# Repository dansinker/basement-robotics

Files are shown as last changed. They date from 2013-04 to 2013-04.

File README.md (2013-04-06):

Basement Robotics: A 3d printed, arduino controlled robot arm
=================

My image

So I built a little robot arm in my basement. All the parts that aren't motors are 3d printed. This repo, like the arm itself, is still a work in progress.

What's in this Repo?
-----------
This repo contains all files necessary to print the 3d arm parts and to program your Arduino to control the arm. Naturally, you will need to consult the shopping list for the various bits and pieces you're going to need to actually build the thing. Most importantly, this repo contains
* [Knob_robotclaw.ino](https://github.com/sinker/basement-robotics/blob/master/Knob_robotclaw.ino) this is the sketch to load into your Arduino.
* [stl_files_for_arm](https://github.com/sinker/basement-robotics/tree/master/stl_files_for_arm) These are every STL file needed to create 3d prints of the arm parts. There are a lot of files that could probably be brought into Makerware (or equivalent) and printed together. I haven't created any massive grouped files just because so many of these pieces had to be build separately and tweaked until they were right.

What's not in this Repo?
-----------
Check the Todo List at the bottom.

Shopping list
---------
* 1 Arduino, obviously.
* A good-sized breadboard.
* 4 hobbyist small-servos. [I bought from Sparkfun](https://www.sparkfun.com/products/9065), and these fit snugly the arms.
* 1 small stepper motor. [Again, Sparkfun](https://www.sparkfun.com/products/10551), and the base is sized to precisely fit this motor.
* 1 stepper motor controller. The code in this sketch is for controlling the [EasyDriver Stepper Motor](https://www.sparkfun.com/products/10267).
* 4 potentiometers. I am using three knobs for wrist, elbow, and shoulder control, and then one slide pot for the claw. You could also use a joystick, or all sliders, or whatever you want. 
* Jumper cable extensions. You're going to be creating a ratsnest of cables and, if you want the arm to have full movement, you're going to need to extend the servo connections and the stepper motor wire at a bare minimum.

Alternate Designs
---------
**Servo for the Base Rotation** You could very easily modify the base to be servo-controlled instead of stepper controlled. This has a number of plusses, mainly centered around exact numerical control of position. I personally found that the servos I had felt a little under-powered for rotating the entire arm, and also didn't give me a full 180 degree of motion because of the gear ratio I was using. A stepper, at the end of the day, got the job done easier. 

**Rotational wrist** One thing I don't think I'm building, but would love to see, is a wrist that can be rotated across the claw's center access.

**Linear claw motion** I'm still going to work on this one. I would like to modify the claw design to open and close completely linearly instead of the more pincer-like current design. 

TODO LIST
--------

* ~~upload all stl files~~ and images of each piece
* ~~create shopping list~~
* create circuit diagram
* assembly instructions
* ~~alternative design thoughts~~

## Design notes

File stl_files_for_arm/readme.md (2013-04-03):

Hi there. 

So these are the final STL files used in the robot pictured at the root of this repo. They were all created in (soon-to-be-late, great) Tinkercad. I will include links to the Tinkercad files themselves in this Readme, but since, well, the fucking site is shutting down this year, these links won't be useful for long.

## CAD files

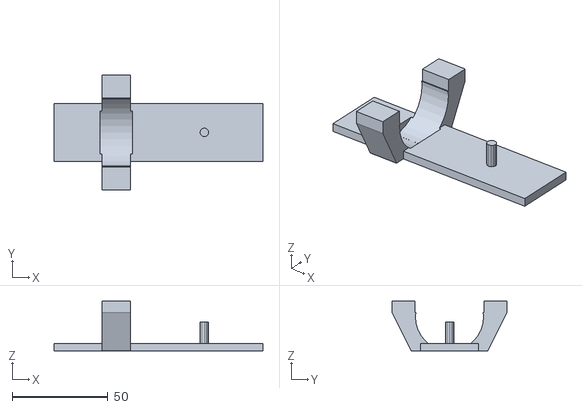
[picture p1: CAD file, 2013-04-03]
stl_files_for_arm/robot_arm_base_stepper.stl
109.0 x 60.0 x 26.0

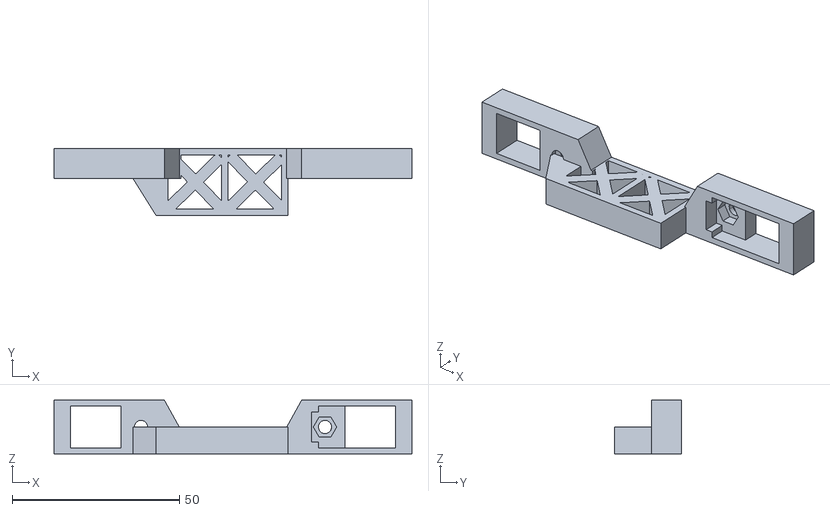
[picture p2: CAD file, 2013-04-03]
stl_files_for_arm/robot_arm_elbow__wrist.stl
107.0 x 20.0 x 16.0

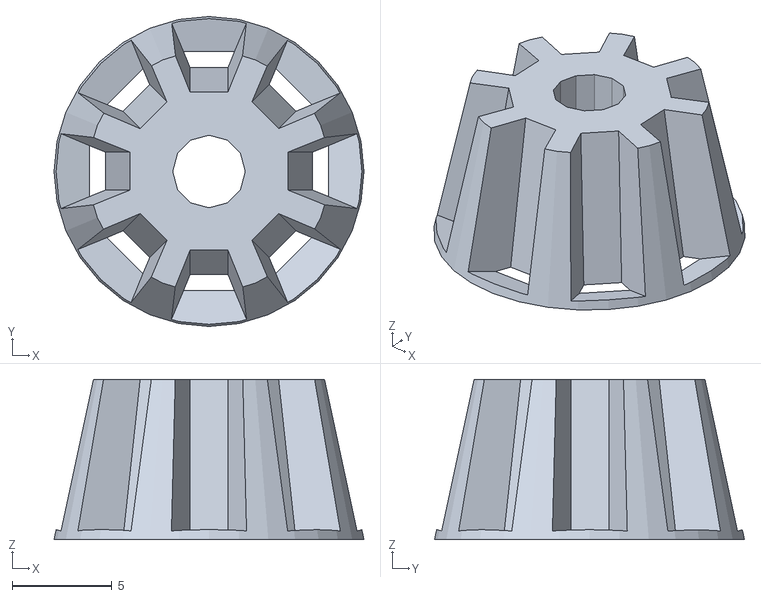
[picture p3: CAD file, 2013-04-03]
stl_files_for_arm/robot_base_rotation_gear.stl
15.5 x 15.5 x 8.00

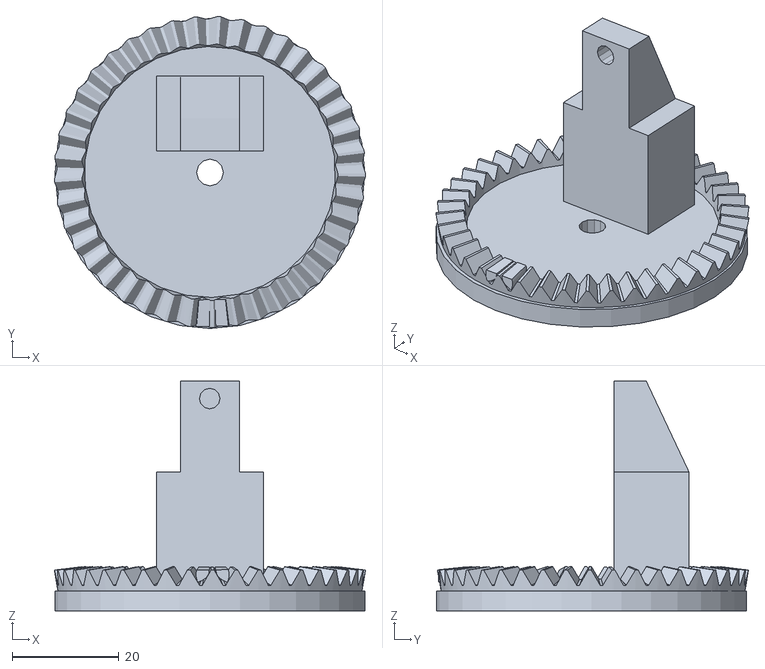
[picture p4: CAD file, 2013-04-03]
stl_files_for_arm/robot_arm_base_stepper_height.stl
58.2 x 58.4 x 43.0

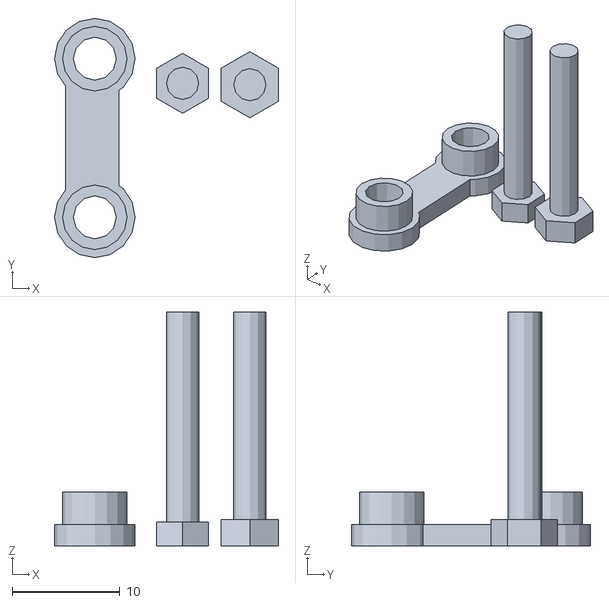
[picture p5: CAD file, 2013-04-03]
stl_files_for_arm/pins_to_connect_pincers.stl
20.8 x 22.2 x 21.8

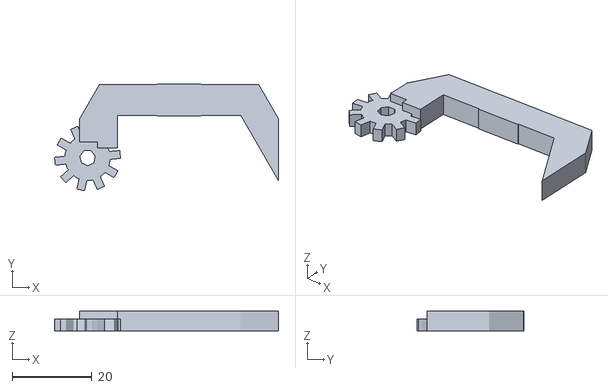
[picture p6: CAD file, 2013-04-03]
stl_files_for_arm/left_pincer.stl
56.3 x 26.8 x 5.00

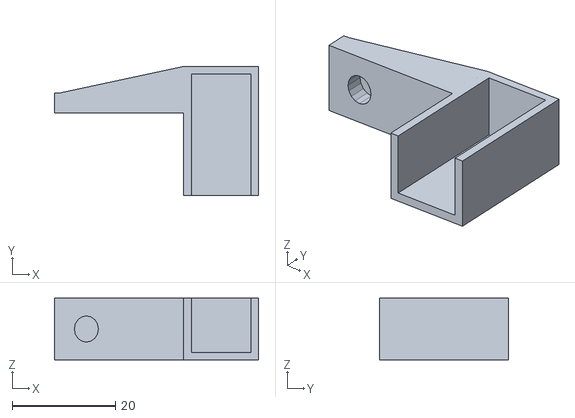
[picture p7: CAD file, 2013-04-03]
stl_files_for_arm/claw_holder.stl
39.5 x 25.0 x 12.0

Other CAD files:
stl_files_for_arm/right_pincer.stl

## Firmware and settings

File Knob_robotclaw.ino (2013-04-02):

// Controlling a servo position using a potentiometer (variable resistor) 
// by Michal Rinott <http://people.interaction-ivrea.it/m.rinott> 

#define DIR_PIN 6
#define STEP_PIN 7

#define BUTTON_PIN 3 //connect button from 3 to ground

boolean pressed = false;

int oneway = 0;

#include <Servo.h> 
 
Servo myservo;  // this is the claw 
Servo myservo2; // this is the elbow
Servo myservo3; // this is the shoulder
Servo myservo4; // this is the wrist
 
int potpin = 0;  // this is the slide for the claw
int potpin2 = 1;  // this controls the elbow
int potpin3 = 2; // this controls the shoulder
int potpin4 = 3; // this controls the wrist

int val;    // variable to read the value from the analog pin 
int val2; // reading from the other pot
int val3; // reading from third pot
int val4; // reading from fourth pot
int comboval = 0;
int wristval = 0;
 
void setup() 
{ 
  myservo.attach(9);  // claw servo on pin 9
  myservo2.attach(10); // elbow servo to pin 10
  myservo3.attach(11); // shoulder servo on pin 11
  myservo4.attach(8); // the wrist servo on pin 8
  
  pinMode(DIR_PIN, OUTPUT);
  pinMode(STEP_PIN, OUTPUT);

  pinMode(BUTTON_PIN, INPUT);
  digitalWrite(BUTTON_PIN, HIGH);
  
} 
 
void loop() 
{ 
  val = analogRead(potpin);            // reads the value of the potentiometer (value between 0 and 1023) 
  val = map(val, 0, 1023, 95, 0);     // scale it to use it with the servo (value between 0 and 180) 

  myservo.write(val);                  // sets the servo position according to the scaled value                           // waits for the servo to get there 
  
  val2 = analogRead(potpin2);            // reads the value of the potentiometer (value between 0 and 1023) 
  val2 = map(val2, 0, 1023, 95, 0);     // scale it to use it with the servo (value between 0 and 180) 

  myservo2.write(val2);                  // sets the servo position according to the scaled value 
 
  val3 = analogRead(potpin3);            // reads the value of the potentiometer (value between 0 and 1023) 
  val3 = map(val3, 0, 1023, 95, 0);     // scale it to use it with the servo (value between 0 and 180) 

  val4 = analogRead(potpin4);            // reads the value of the potentiometer (value between 0 and 1023) 
  val4 = map(val4, 0, 1023, 160, 0);     // scale it to use it with the servo (value between 0 and 180) 
  
  wristval = (val4-val3);

  myservo4.write(wristval);                  // sets the servo position according to the scaled value 

  comboval = (val3+val2); // when  pot 3 is moved, it also moves servo 2 in order to keep the arm horizontal. this does that math.

  myservo3.write(comboval);                  // sets the servo position according the movement in pot C, and also moves the upper arm servo. 



  
  checkButton(); //see if button pressed, and rotate if is

 
} 

void checkButton(){

  if(digitalRead(BUTTON_PIN) == LOW && !pressed && oneway == 0){
    //button pressed so it is connected to gnd - LOW
    pressed = true;
    oneway = 1;
    rotate(1000, .15); //rotate 50 steps at 1/4 speed
  }
  if(digitalRead(BUTTON_PIN) == LOW && !pressed && oneway == 1) {
    pressed = true;
    oneway = 0;
    rotate(-1000, .15); //rotate 50 steps at 1/4 speed
  }
  else if(digitalRead(BUTTON_PIN)){
    //not pressed, restart pressed VAR
    pressed = false;
  }
}

void rotate(int steps, float speed){
  //rotate a specific number of microsteps (8 microsteps per step) - (negitive for reverse movement)
  //speed is any number from .01 -> x1 with 1 being fastest - Slower is stronger
  int dir = (steps > 0)? HIGH:LOW;
  steps = abs(steps);

  digitalWrite(DIR_PIN,dir);

  float usDelay = (1/speed) * 70;

  for(int i=0; i < steps; i++){
    digitalWrite(STEP_PIN, HIGH);
    delayMicroseconds(usDelay);

    digitalWrite(STEP_PIN, LOW);
    delayMicroseconds(usDelay);
  }
}

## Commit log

2013-04-02 added the arduino code
2013-04-02 starting to add the stl files
    [claw_holder(1).stl, copy_of_robot_arm_base_short(2).stl, copy_of_robot_arm_coming_off_base.stl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]
2013-04-03 added a readme for the stl directory
2013-04-03 updated every shape file
    [claw_holder(1).stl, claw_holder.stl, copy_of_robot_arm_base_short(2).stl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]
